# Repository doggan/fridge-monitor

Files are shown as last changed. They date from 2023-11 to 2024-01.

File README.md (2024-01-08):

# ❄️ Fridge Monitor ❄️

A monitoring system for refrigerators.

Using Raspberry Pi Pico W and sensor hardware, we can monitor the status of a refrigerator. This data can be used to help modify user behavior and improve energy conservation (e.g. keeping the refrigerator door open too long, or opening it too often).

## Features
- Play an alert sound if the refrigerator door is open too long.
- Monitor refrigerator temperature over time.
- Monitor refrigerator door open/close events over time.

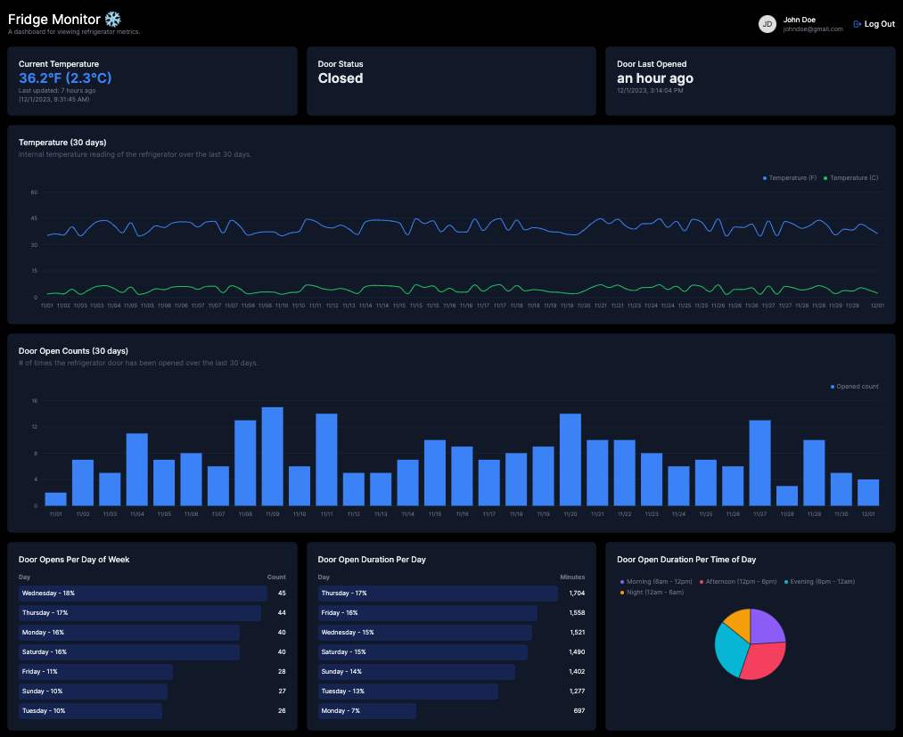
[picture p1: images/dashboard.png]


## Components
- `/dashboard` - A Front-End for viewing data interactively.
- `/device` - Code for running on the Raspberry Pi hardware.
- `/infrastructure` - IaC (Infrastructure as Code) for configuring the cloud components (currently incomplete).
- `/schematic` - Hardware schematics for how to wire the Raspberry Pi and sensors.

### System Overview
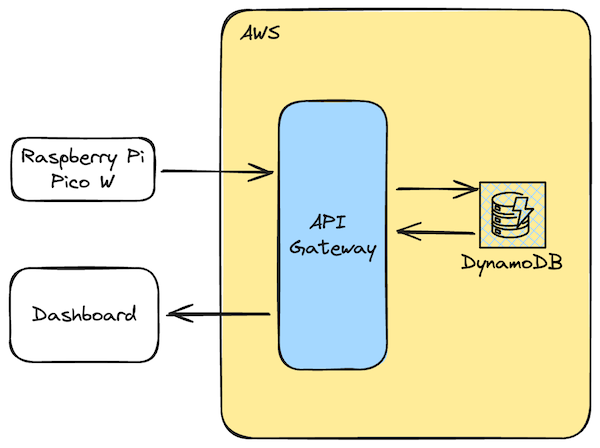
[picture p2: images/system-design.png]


## Usage

### Dashboard

For local development:
- Create a `.env.local` file with the following values:
    - `NEXT_PUBLIC_BASE_API_URL=XXXXX` - This can be anything when using mock data, since the actual device id is not used.
    - `NEXT_PUBLIC_BASE_API_URL=http://localhost:3001` - The default API URL for retrieving data.
    - For Auth0 login, add:
        - `AUTH0_SECRET='XXXXX'`
        - `AUTH0_BASE_URL='http://localhost:3000'`
        - `AUTH0_ISSUER_BASE_URL='XXXXX'`
        - `AUTH0_CLIENT_ID='XXXXX'`
        - `AUTH0_CLIENT_SECRET='XXXXX'`
- Run the project:
  - `npm run dev`
- Start a local API server to mock data, available at [http://localhost:3001](http://localhost:3001) by default:
  - `npm run mock-server`
- Access [http://localhost:3000](http://localhost:3000) to view the result.

For deploying to Vercel, the above environment variables must be defined.

### Device

- Configure the hardware as illustrated in the schematic below.
- Modify the required constants in `config.py`.
- Deploy code to hardware (Raspberry Pi Pico W).

#### Schematic

Notes:
- For door sensors, I used MC-38 Wired Door Sensor Magnetic Switch.
- For door buzzer, I used an Active Buzzer.
- For temperature sensor, I used a DS18x20.
  - The official spec says a 4.7K pullup resistor is needed from data to the 3.3V power. Using a 4.7K resistor didn't work for me - the sensor could no longer be detected. I think it's due to the length of my particular sensor wire, so I reduced it to 2.2K in my final configuration.

Diagrams:
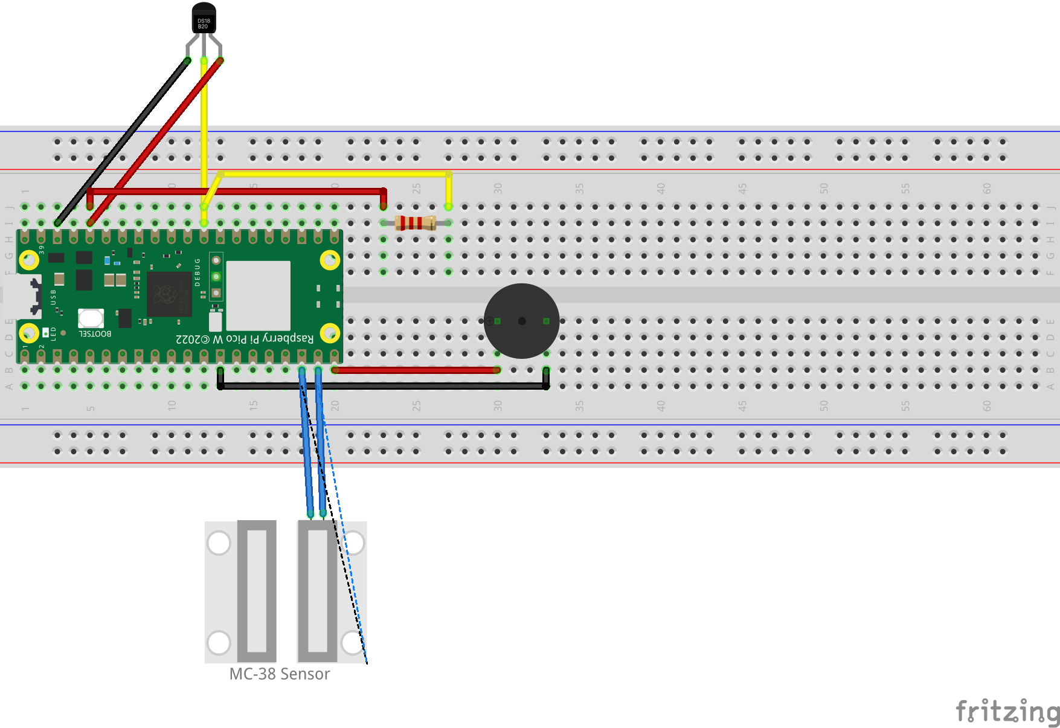
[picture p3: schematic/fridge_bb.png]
breadboard

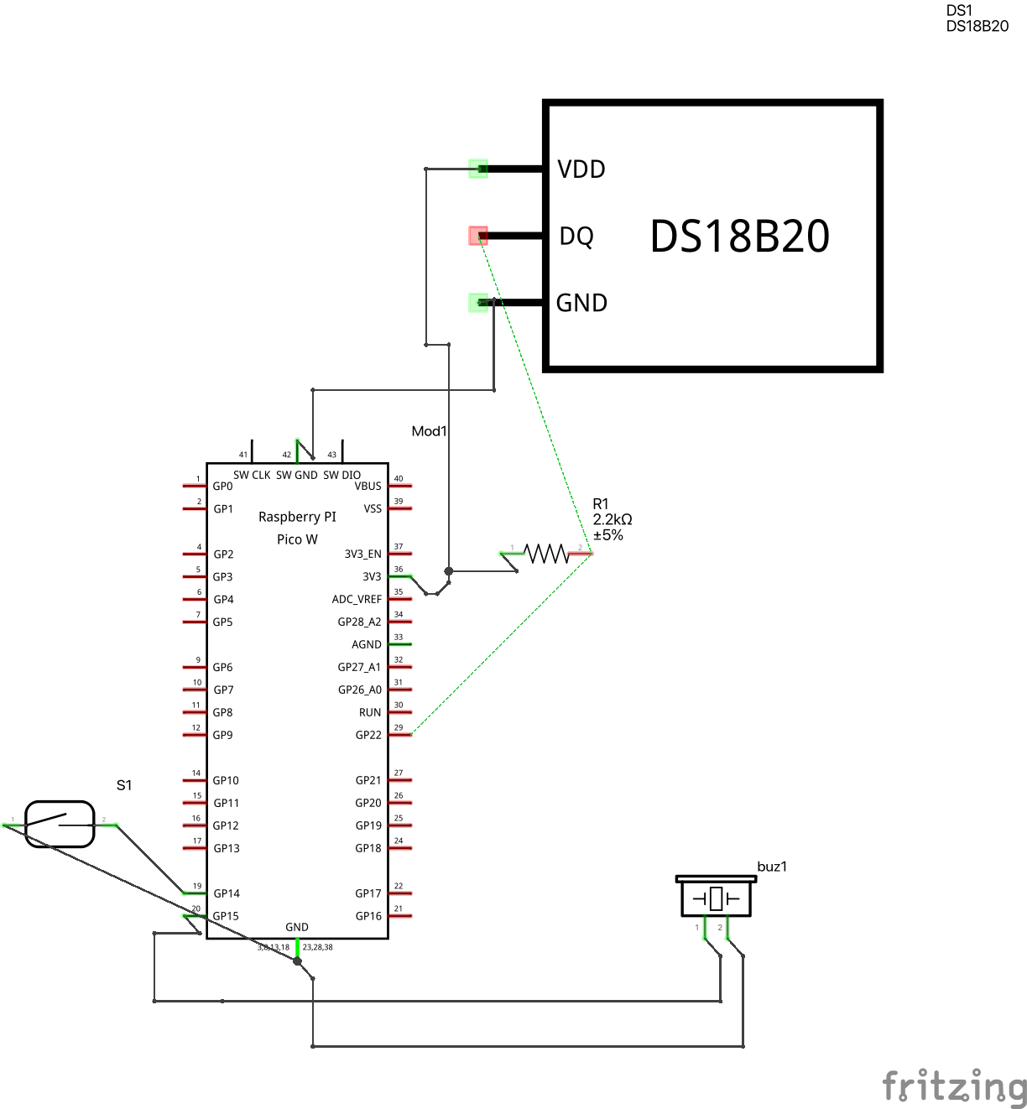
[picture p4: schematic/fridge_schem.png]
schematic


## Potential Future Improvements

- Add a weekly report email generator to get updates and trends on usage without having to view the dashboard (lambda function).
- Dashboard: periodically refresh data without having to reload page.
- Make the `/temperature-events` API paginated similar to `/door-events`.

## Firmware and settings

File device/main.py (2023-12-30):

from machine import Pin, PWM, Timer
import machine
import time
import ntptime
import json
import ubinascii
from utime import sleep
import urequests
import onewire, ds18x20
from time import sleep

import wifi
from config import config
import logger

# For development only.
#logger.enable_log_file()
#logger.info("---- begin execution -----")

DEVICE_ID = ubinascii.hexlify(machine.unique_id())
logger.info(f"Device ID: {DEVICE_ID}")

API_URL_DOOR_EVENTS = config["API_ENDPOINT"] + "/door-events"
API_URL_TEMP_EVENTS = config["API_ENDPOINT"] + "/temperature-events"
BUZZER_FREQUENCY = 262 # C4 note == 262

def buzzer_on(frequency):
    DOOR_BUZZER_PIN.duty_u16(1000)
    DOOR_BUZZER_PIN.freq(frequency)

def buzzer_off():
    DOOR_BUZZER_PIN.duty_u16(0)

DOOR_PIN = Pin(14, Pin.IN, Pin.PULL_UP)

door_buzzer_pin = Pin(15, Pin.OUT)
DOOR_BUZZER_PIN = PWM(door_buzzer_pin)
buzzer_off()

ds_pin = Pin(22)
DS_SENSOR = ds18x20.DS18X20(onewire.OneWire(ds_pin))
DS_ROMS = DS_SENSOR.scan()

if len(DS_ROMS) == 0:
    logger.info("Error: No DS Roms detected.")
    
def setup_time():
    logger.info("Setting NTP Time...")
    
    i = 0
    while 1:
        try:
            # Update the current time on the board using NTP.
            # Needed for SSL connections and timestamp accuracy.
            ntptime.settime()
            break
        except OSError as e:
            print(str("ntptime errornr="),e)
            i += 1
            time.sleep(i)

def get_now():
    # For now, just returning the ISO-8601 string in UTC time, since
    # we store UTC time on the server. Our FE can convert to local timezone
    # since we're only dealing with a single device. Ideally, we can register
    # the device timezone, store server data in UTC, and have the FE display logic
    # convert to the device's timezone.
    local_time = time.gmtime()
    iso_time = "{:04d}-{:02d}-{:02d}T{:02d}:{:02d}:{:02d}+00:00".format(
        local_time[0], local_time[1], local_time[2], 
        local_time[3], local_time[4], local_time[5])
    return iso_time

    """
    utcOffsetSeconds = config["TIMEZONE_UTC_OFFSET_SECONDS"]

    # Split out into hour/minute components.
    # 8:30 (8 hours 30 minute UTC offset) -> 30600 utcOffsetSeconds
    # utcOffsetHours == 8
    # utcOffsetMinutes == 30
    utcOffsetHours = int(utcOffsetSeconds / 60 / 60)
    utcOffsetMinutes = (utcOffsetSeconds - (utcOffsetHours * 60 * 60)) // 60
    
    local_time = time.localtime(time.time() + config["TIMEZONE_UTC_OFFSET_SECONDS"])
    
    # ISO 8601 format, e.g. 2023-11-15T17:19:13.233-08:00
    iso_time = "{:04d}-{:02d}-{:02d}T{:02d}:{:02d}:{:02d}{}{:02d}:{:02d}".format(
        local_time[0], local_time[1], local_time[2], 
        local_time[3], local_time[4], local_time[5],
        "+" if utcOffsetSeconds >= 0 else "-", abs(utcOffsetHours), abs(utcOffsetMinutes))
    return iso_time
    """


def on_door_event(event_type):
    event_data = json.dumps({
        "deviceId": DEVICE_ID,
        "timestamp": get_now(),
        "eventType": event_type,
    })
    logger.info("on_door_event: %s", event_data)
    
    headers = {'Content-Type': 'application/json'}

    try:
        response = urequests.post(API_URL_DOOR_EVENTS, data=event_data, headers=headers)
        if response.status_code != 200:
            logger.info("Door event post failure: %s - %s", response.status_code, response.text)
    finally:
        response.close()

def on_temperature_event(temp):
    event_data = json.dumps({
        "deviceId": DEVICE_ID,
        "timestamp": get_now(),
        "value": temp,
    })
    logger.info("on_temperature_event: %s", event_data)
    
    headers = {'Content-Type': 'application/json'}

    try:
        response = urequests.post(API_URL_TEMP_EVENTS, data=event_data, headers=headers)
        if response.status_code != 200:
            logger.info("Temperature event post failure: %s - %s", response.status_code, response.text)
    finally:
        response.close()


def read_temperature(timer):
    DS_SENSOR.convert_temp()
    time.sleep(1)
    for rom in DS_ROMS:
        temp = DS_SENSOR.read_temp(rom)
        on_temperature_event(temp)
        break


def main_loop():
    prev_door_status = DOOR_PIN.value()
    door_last_open_time = None
    is_door_buzzer_on = False

    while True:
        door_status = DOOR_PIN.value()
        if door_status != prev_door_status:
            if door_status:
                on_door_event("open")
                door_last_open_time = time.ticks_ms()
            else:
                if is_door_buzzer_on:
                    buzzer_off()
                    is_door_buzzer_on = False
                    #logger.info("Buzzer OFF")
                    
                on_door_event("close")
                door_last_open_time = None

            prev_door_status = door_status

        if door_last_open_time is not None and not is_door_buzzer_on:
            time_open = time.ticks_diff(time.ticks_ms(), door_last_open_time)
            time_before_warning_ms = config["DOOR_OPEN_TIME_BEFORE_WARNING_IN_SECONDS"] * 1000
            if time_open > time_before_warning_ms:
                buzzer_on(BUZZER_FREQUENCY)
                is_door_buzzer_on = True
                #logger.info("Buzzer ON")
                
        time.sleep(0.1)

# TODO: wlan re-connect logic
wlan = wifi.connect_wlan()

setup_time()

logger.info("Application started.")

temperature_read_period_ms = config["TEMPERATURE_READ_FREQUENCY_IN_SECONDS"] * 1000
logger.info("Temperature read period: %s seconds", config["TEMPERATURE_READ_FREQUENCY_IN_SECONDS"])

temperature_timer = Timer(-1)
temperature_timer.init(period=temperature_read_period_ms, mode=Timer.PERIODIC, callback=read_temperature)

try:
    main_loop()
except KeyboardInterrupt:
    logger.info("Application terminated.")
    temperature_timer.deinit()

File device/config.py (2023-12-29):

# These values must be configured for usage.
config = {
    # Network name.
    "WLAN_SSID": 'XXXXX',
    # Network password.
    "WLAN_PASSWORD": 'XXXXX',
    
    # API endpoint URL for AWS API Gateway to post events.
    "API_ENDPOINT": "https://XXXXX.us-east-1.amazonaws.com/release",

    # Number of seconds the door is open before playing the warning buzzer.
    "DOOR_OPEN_TIME_BEFORE_WARNING_IN_SECONDS": 15,
    
    # How often to collect temperature data.
    "TEMPERATURE_READ_FREQUENCY_IN_SECONDS": 60,
    
    #"TIMEZONE": "America/Los_Angeles",
    # TODO: changes between -7 and -8 depending on daylight savings. need a better automated way to handle this,
    # but the pico doesn't have timezone data. we could query an external API periodically to read this in.
    #"TIMEZONE_UTC_OFFSET_SECONDS": -8 * 60 * 60,
}

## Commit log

2023-11-14 Import MQTT lib for device
2023-11-15 Import schematic diagram
    [fridge.fzz]
2023-11-16 Working through time issues
    [fridge.fzz]
2023-11-16 Device ID and gmt time
2023-11-16 Import libs for temperature sensor
2023-11-17 Add keepalive ping for idle client to prevent disconnect
    [main.py]
2023-11-19 Add some device logging
2023-11-21 switch to robust mqtt; add buzzer
    [main.py]
2023-11-30 Current temp and door status components.
2023-12-01 Login button styling
2023-12-23 Update diagram
    [fridge.fzz]
2023-12-28 Switch to API gateway POST instead of mqtt
2023-12-29 Fix temperature API endpoint
2023-12-29 Temperature logic
2023-12-30 Temperature events
2023-12-30 Hardware schematics
    [fridge.fzz]
2024-01-01 Sort before stripping year
    prevents sorting issues when switching to a new year :)
